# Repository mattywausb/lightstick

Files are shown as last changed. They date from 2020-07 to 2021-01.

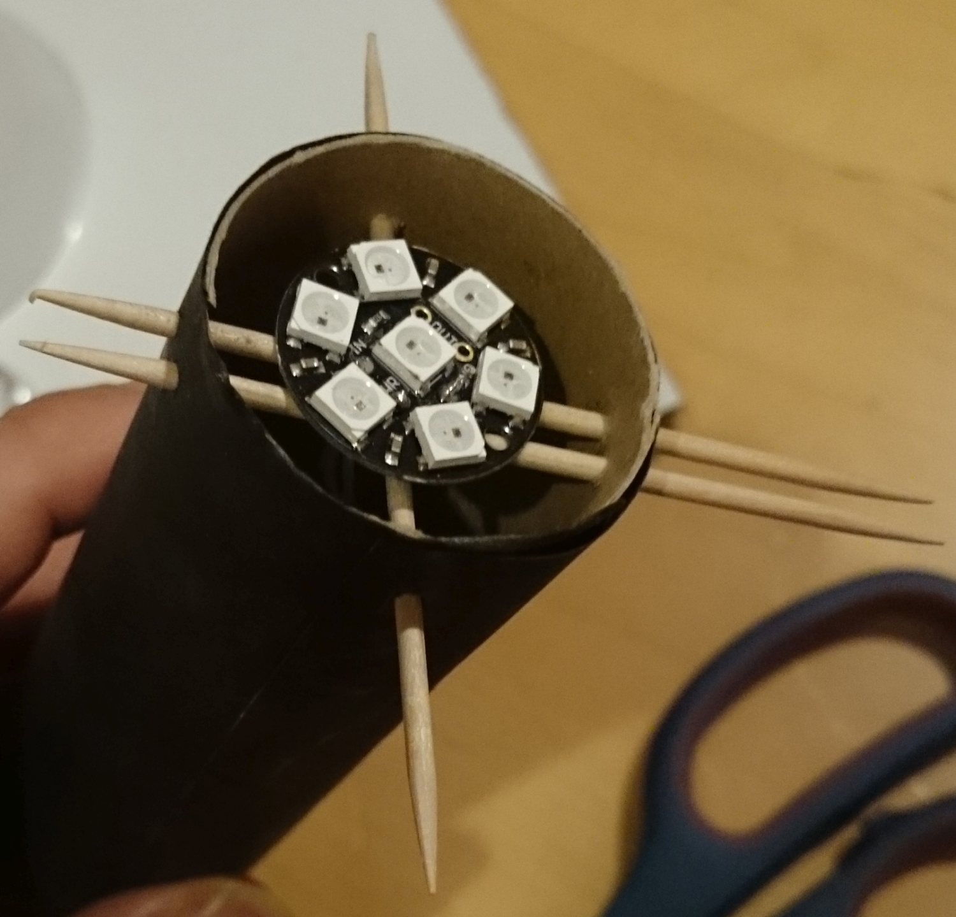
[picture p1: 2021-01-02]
docs/Head_assembly_1.jpg

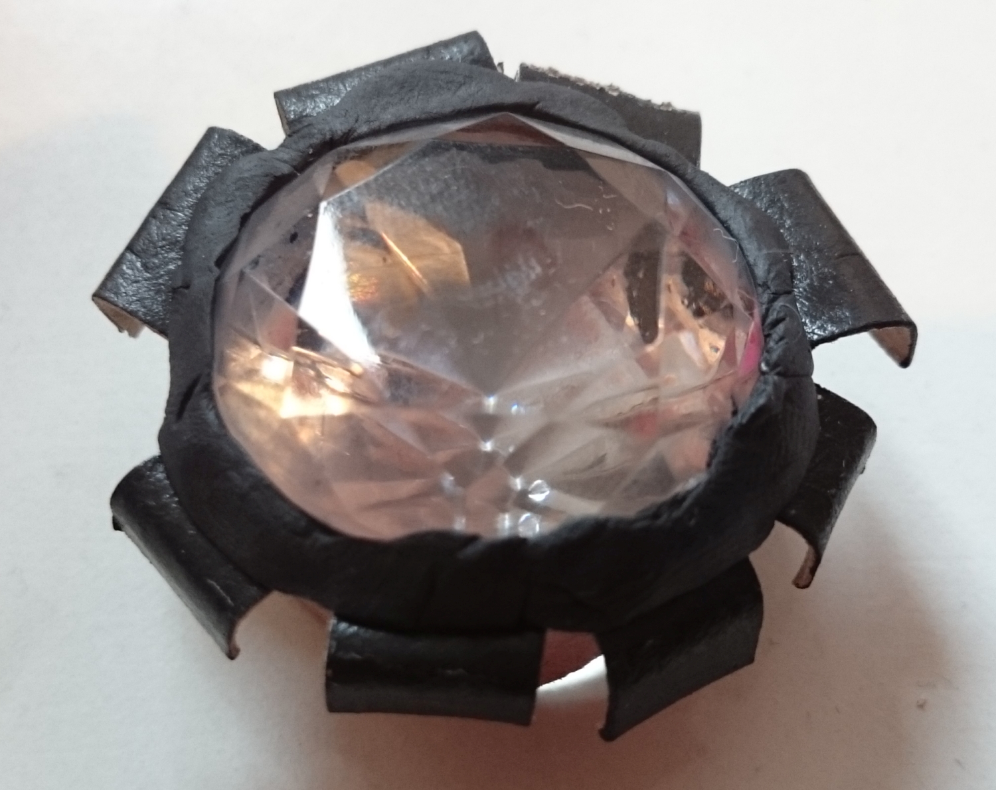
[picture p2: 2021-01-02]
docs/Optical_unit_using_CardboardSUGRU.jpg

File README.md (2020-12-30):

# ElBanquos K-Pop Lightstick
A DIY "ightstick" with multiple light effects and song specific light show presets

# Motivation
My daughter and her friends are huge fans of K-POP music and wanted to have these fancy light sticks, that are common in the concerts of K-POP groups. To be independent from an provider and restricted to one group, we decided to make our own with the following features
* Lot's of different multicolor light patterns to choose from
* Song specific presets, to have pattern changes aligned with the music 
* Smartphone compatible webinterface for song selection and pattern programming
* BPM Detection and synchronization with integrated button
* on the fly programming of new light shows over web interface
* save and load songs to/from the flash memory
* connects to existing WLAN or creates its own Access Point

# Material
* ESP8266 NodeMCU Board or D1 Mini
* Neopixel Jewel
* Pushbutton
* Small USB Power Pack or long USB Cable
* Tube that can hold NODEMCU and power pack
* small facette crystal
* transparent sphere

For more information check out my [arduino project page]( https://create.arduino.cc/projecthub/mattywausb/k-pop-lightstick-personal-lightshow-641dac)

# Software Architecture
The software is split up into the following modules
* Main Module: Coordination of processing time, Translation of input events (Button, Serial Input) into changes of pattern, Mangement of pattern sequences
* Input Module: Detection of button changes (and serial input if activated)
* WebUi Module: Redering of the WebUI and translation of WebUI Form Inputs to the main main module and management of network connection
* Lamp Module: Class to model a Hue/Saturation/Value Lamp and translate color into RGB 
* Output Module: Controlling the Lamps and Pixels, Stepping and looping through a defined pattern until instructed otherwise. Contains functions for generic chase patterns and defines the available pattern presets (Chase mode, beat fraction tempo, color palette)
* Song Catalog Module: Manages reading and saving of songs patterns to the flash memory file system

# What you will find in the repository
* Main Arduino sketch for the firmware (the_light_stick)
* Arduino sketch to format and prepare the flash memory file system (song_catalog_init)
* Additional sketches for separate developtment of light pattern(Arduino UNO compatible) and web interface(only on ESP8266)
* Additional sketches for simple demos of light control and web interface
* Documentation
  * Fritzing sketch for wireing used in the implementation
  * Manuals
  * Schematic

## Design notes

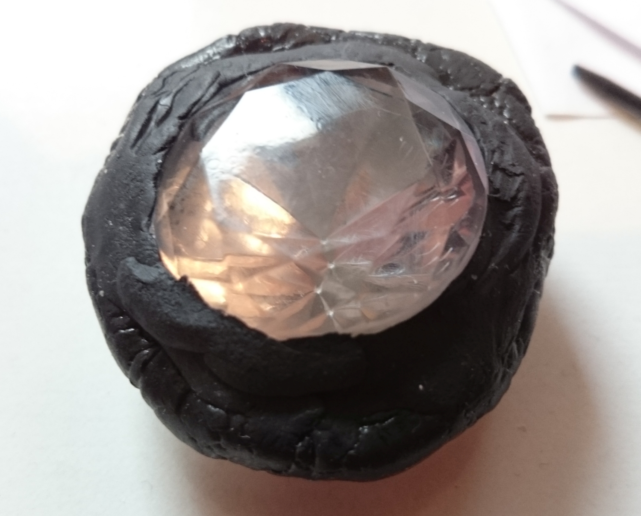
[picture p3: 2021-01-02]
docs/Optical_unit_using_FIMOSUGRU.jpg

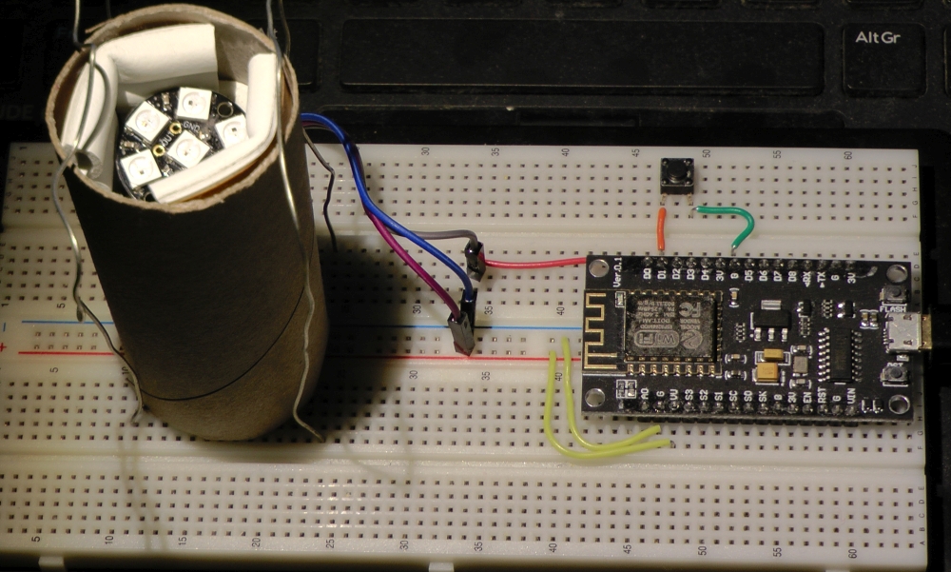
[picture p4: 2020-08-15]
docs/development_mockup.jpg

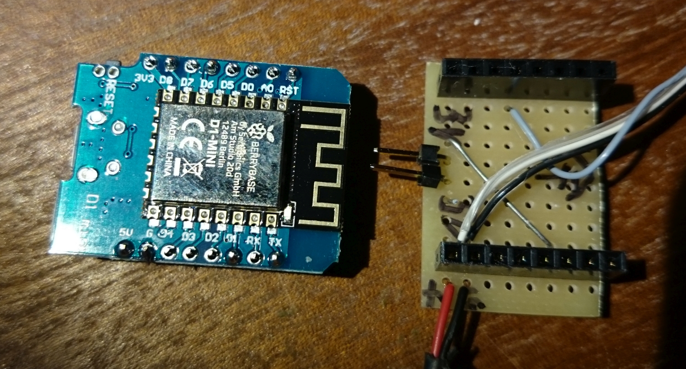
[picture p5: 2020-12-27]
docs/D1_mini_pcb_front.jpg

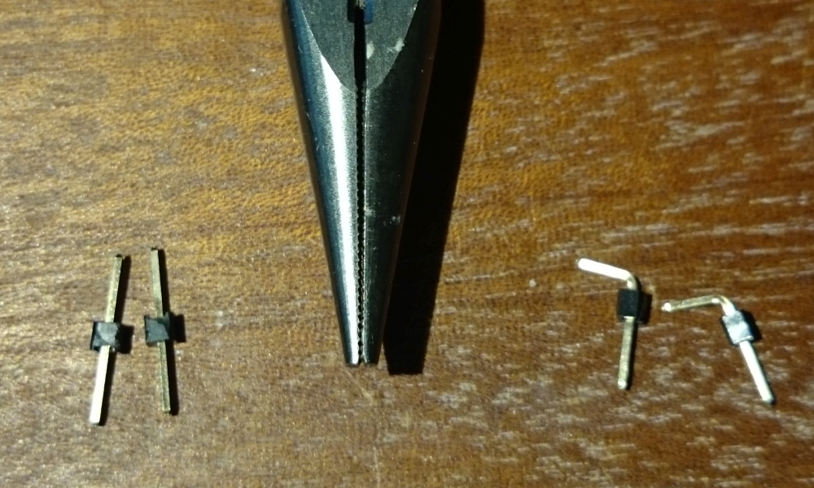
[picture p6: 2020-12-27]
docs/Crafting_button_connector.jpg

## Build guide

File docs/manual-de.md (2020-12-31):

# Personal K-Pop Lightstick - Anleitung

Mit dem "Personal K-Pop Lightstick" hat man seine eigene Lichtshow verfügbar. Im Gegensatz zu kommerziellen Produkten funktioniert er unabhängig von einer Konzertveranstaltung. Die Einstellung und Steuerung erfolgt über eine Webbrowseroberfläche. Er bietet folgende Funktionen 
* Synchronisation mit dem Beat und Musikverlauf über eingebauten Taster
* Direkte Auswahl eines Musters und Farbzusammenstellung
* Abruf von vorbereiteten Abläufen für bestimmte Lieder
* Individuelle, taktgenaue Programmierung eines Ablaufs

## Einschalten

Der Stick wird eingeschaltet, indem man den USB Stecker aus dem unteren Stabende herausholt und mit einer passenden Stromversorgung verbindet. Sofern diese kompakt genug ist, kann man sie direkt im Stick deponieren und den Deckel wieder verschließen.

Sowie der Lightstick Strom hat sucht er die Verbindung zum zuletzt kontaktierten WLAN. In dieser Zeit leuchtet er schwach in Orange. Kann er das WLAN nicht erreichen versucht er Kontakt mit einem fest codierten WLAN aufzunehmen. 
War der Verbindungsaufbau erfolgreich, wird dies durch ein schwaches grünes Blinken mitgeteilt.

Kann er kein WLAN erreichen, eröffnet der Stick eine eigene WLAN Zelle. (SSID:"Lightstick-xxxxxxxx-AP" Passwort:"letsparty" (xxxxxx=Seriennummer des eingebauten Controllers)) und ist dort unter der Adress 192.168.4.10 erreichbar.

Wenn beim Einschalten/Einstecken der USB Verbindung der Taster gehalten wird, umgeht der Stick den Versuch ein WLAN zu erreichen und baut sofort seine eigene WLAN Zelle auf.

Das ein eigenes WLAN eingerichtet wurde, wird durch ein schwaches blaues Blinken mitgetilt.

Sollte der Stick auch keinen eigenen AP aufbauen können, blink er rot und ist dann leider nicht bedienbar.

## Zugriff auf die Bedienoberfläche
Für den Zugriff benötigt man einen Browser auf einem beliebigen Gerät, das mit dem gleichen Netzwerk verbunden ist, wie der Stick.

Die im Browser einzugebende IP Adresse besteht aus 4 Zahlen, die jeweils von einem Punkt getrennt sind (z.B. 192.168.4.10) und wird vom Stick wie folgt als sich wiederholender Ablauf verschiedener Muster dargestellt.
* 8 Beats schwach grün/Blau = WLAN Modus (siehe oben)
* 2 Beats dunkel weiß>pink = Startzeichen für erste Zahl
* n rotierende Schritte in rot (n= Ziffer 1)
* 2 Beats dunkel pink 
* n rotierende Schritte in gelb (n= Ziffer 2)
* 2 Beats dunkel pink 
* n rotierende Schritte in blau (n= Ziffer 3)
* 2 Beats dunkel pink 
* 2 Beats dunkel weiß>pink = Startzeichen für zweite Zahl
* n rotierende Schritte in rot (n= Ziffer 1)
...

Um eine Null als Ziffer darzustellen wird mit einem kräftigen Pink einmal aufgeblendet. Die Ziffern 2 und 3 werden nicht genutzt, wenn sie für die Zahl nicht notwendig sind.

## Auswahl eines Pattern (Musters)
Ein Pattern definiert, welche der eingebauten LED wann und wie lange leuchten. Dies erfolgt bezogen auf den laufenden Takt, d.h. das Pattern passt sein Lauftempo der Beatzahl(BPM) an, die über den Taster ermittelt wird oder von einem vorigen Song noch eingestellt ist. 

## Zusammenstellung einer Farbpalette
Die Farbe der LED wird in der Regel durch die eingestellte Farbpalette festgelegt. Dabei wird vom eingestellten Pattern bestimmt ob mehrere Farben der Palette gleichzeitig genutzt werden und in welchem Tempo zum nächsten Platz der Palette geschaltet wird. 

Mit Auswahl einer Farbe auf der Weboberfläche wird die Farbpalette geleert und der erste Platz der Palette auf diese Farbe gesetzt. Das laufende Pattern ist dann einfarbig (Whipe wird dann nur diese Farbe zeigen). Wird das '+' Zeichen rechts neben der Farbe gewählt, so wird diese Farbe an die Palette angehängt und die Pattern greifen das entsprechend auf.

Je nach Pattern kann es interessant sein, die gleiche Farbe mehrfach hintereinander in die Palette  einzubauen. (z.B. Gelb, Blau, Blau,Blau bei "Fade", leuchtet alle 4 Beats einmal Gelb und ansonsten Blau)

### Die Pattern:
* Pulse - Kurzes Aufblitzen auf dem Beat (nutzt 2 Paletteneinträge)
* Whipe - leds innerhalb eines Beats nacheinander auf Folgefarbe schalten 
* Wave - leds nacheinander innerhalb eines Beats ein-  und im Folgebeat wieder ausschalten, dann zum nächsten Paletteneintrag wechseln
* Orbit - einfarbig rotierende Lichter. Die mittige Led blinkt auf Step 1 und 2 von 8)
* Disco - Wie Orbit, allerdings werden 3 einträge der Farbpalette auf die 3 aktiven Led verteilt
* Sparkle - Aufblitzen zufälliger LED mit einer Zufallsfarbe aus 3 Paletteneinträgen

Folgenden Pattern ignorieren die Farbpalette 

 Rainbow - Volles Farbspektrum 
 Quater - Ausschnitt aus dem Spektrum der sich dann verschiebt
 Flat - es wird nur eine Farbe des Spektrums gezeigt  und weitergeschaltet

## Synchronisationstaster
Mit dem Taster werden folgende Funktionen ausgelöst.
* 1xTippen - Beatposition festlegen / korrigieren 
* 4x regelmäßig Tippen - Tempo messen und einstellen (unregelmäßiges Tippen führt zu keiner Änderungen) 
* Halten - Aktuelles Pattern wird festgehalten. Mit Loslassen des Tasters wird das nächste Pattern gestartet

## Songprogramm abspielen
Die fest eingebauten Songs werden auf der Weboberfläche als eigene Schaltflächen angezeigt. Mit der Auswahl eines Songs wird dessen Programm sofort aktiviert, dies umfasst das korrekte Tempo (BPM) und eine Abfolge von Mustern und Farben passend zum Songverlauf.
Das Programm beginnt mit einem Muster als Wartschleife, d.h. die Abfolge wird noch nicht abgespielt sondern verweilt auf diesem ersten Muster bis der Taster gedrückt wird.

In der Regel muss der Taster auf Beat 17 (die 1 nach zweimal 8 zählern) des laufenden Songs gedrückt werden um den Ablauf passend zu starten. Die Bedienabfolge wäre also:
* Songprogramm starten (Warteschleife beginnt)
* Song im Abspielprogramm deiner Wahl starten 
* Bis Beat 16 zählen und auf dem Folgebeat den Taster bedienen

### Korrigieren
Mit einem einmaligen kurzen Druck auf den Taster kann der Beat neu synchronisiert werden. Sollte es dazu kommen, dass das Programm insgesamt gegenüber dem Ablauf verschoben ist kann mit etwas Geschickt die Position korrigiert werden.
* Lichtshow ist dem Song voraus: 2-3 Takte vor einem markanten Lichtwechsel (z.B. Refrain) den Taster drücken und halten und mit dem Beat an dem der Wechsel erfolgen soll loslassen
* Lichtshow hängt hinterher: Taster 2,5 Sekunden halten und sofort loslassen. Das Programm springt eine Position vor und ist vermutlich jetzt dem Song voraus. Deshalb gleich wieder den Taster halten und warten bis der nächste Wechsel ansteht

### Wann ist Beat 17 und warum der ?
Manche Songs haben einen Auftakt, was bei unverzüglichem Zählen der Beat zu einem Versatz in den üblichen 8er Gruppen führt. Deshalb gilt folgende Definition:

**Beat 17 ist der erste Beat nach zwei vollständigen 8er Gruppen**. 

Oder auch Beat 1 zum zählen ist der *erste Beat der ersten vollständigen 8er Gruppe*. Vortakte (z.B. die 4 Vortaktbeats von "DNA") zählen also nicht.

Beat 17 war die beste Wahl, da man so über die zwei 8er Gruppe gute Orientierung bekommt und auch bei plötzlichen Songstarts(z.B. aus einer Playlist) noch zeit hat das Programm zu wechseln während man im Kopf noch mitzählt.

Die Warteschleife und ihre Position im Song ist eine Festlegung des jeweiligen Song Programms. Für die leichtere Bedienung wurde Beat 17 festgelegt. Eigene Programme können auch andere Zählpositionen festlegen.

## Eigene Songprogamme eingeben und abspielen
Auf der Weboberfläche gibt es zwei Eingabefelder um das Songprogramm selbst festzulegen. Diese werden bei der Auswahl eines vorbereiteten Songs mit den Programmangaben für diesen Song belegt. Die beiden Textschnipsel kann man aber auch selbst dort editiern oder von einer externen Quelle hineinkopieren. Ein Songprogramm besteht aus zwei Teilen:
* Song Parts: Definieren verschiedene Sätze von Farbpaletten und Mustern die der Song nutzt
* Song Sequence: Legt das Tempo fest und regelt , welcher Song Part für wieviele Beats abgespielt werden soll

### Song Parts
Die Angabe eines Song Parts erfolgt in folgender Syntax:
```
<Part Letter><Pattern preset>/<Speed>:<Color Ppalette>

Beispiel:"A10/4:0  B42/8:2  R30/8:0"
```
* Part Letter: Ein Buchstabe unter dem dieser Part in der Song Sequence angesprochen wird. Gute Praxis sind A B C für Strophenabschnitte R S T für Refrainabschnitte, I J L M für Intro Abschnitte
* Pattern Preset: Die Nummer eines Patternpresets (Legt Pattern und Farbstepping fest)
* Speed: Tempo des Steppings innerhalb des Beats (2=2 Beats(halbe Note), 4= 1 Beat(4tel Note), 8=1/2 Beat(8tel Note), 16, 32,64
* Color Palette: Die Nummer einer der fest programmierten Farbpaletten

### Song Sequence:
Die Song Sequence repräsentiert die Abfolge des Songs. Sie beginnt mit der  BPM Angabe der dann die Songabschnitt folgen. Verschiedene Sonderzeichen markieren spezielle übergeordnete Positionen
```
<bpm> <Part Letter> <Beats><Beats>... <Part Letter>...

Beispiel: "120 A88# A88 B88 A8888 B88 R8888 8888 >A8888 B88 R8888 8888"
```

* Part Letter: Muss einer der Buchstaben aus der "Song Parts" Definition sein
* Beats: Die Beats werden als einstellige Zahlen angegeben und als solche dann für den aktuellen Abschnitt aufaddiert bis ein neuer Buchstabe den nächsten Abschnitt deklariert. (Beispiele: 8888=32 Beats 248 =14 Beats)
* Sonderzeichen #: Der Abschnitt in dem dieses Zeichen steht ist die Warteschleife. Mit dem Tastendruck springt das Programm dann zum nächsten Abschnitt. Die Anzahl an Beats in dem Abschnitt sind dabei irrelevant, sollten aber so angegeben werden, dass man ablesen kann, welcher Beat für den einsatz gewählt werden soll (88 = 16 Beats, Also Beat 17 für den Wechsel)
* Sonderzeichen >: Nach dem Songende wird an diese Stelle zurückgesprungen. So kann eine Endlosschleife einer Folge konstruiert werden. Ohne diese Angabe springt das Programm wieder an den Anfang zurück und in die ggf. dort definierte Warteschleife 

### Fehlerbehandlung
Die Angaben für Song Parts und Song Sequence werden intern bzgl. plausibilität geprüft. Formatfehler führen dazu, dass Teile ignoriert oder auch falsch zugeordnet werden. *Es gibt bisher keine Rückmeldung* ob alle Angaben korrekt waren. Syntaktisch falsche oder inkonsistente Angaben(z.B. Buchstabe doppelt als Song Part genutzt oder nicht als Songpart definiert, unbekannte Farbpalette, unbekannter Pattern Speed) führen zu verschiedenen Phänomenen: Falsche Farbpalette, Falsche Pattern, Falsche Anzahl an Beats bis zum Wechsel

## Songprogramme speichern
Ein Songprogramm kann fest in dem Stick gespeichert und dann über die Auswahlliste wieder abgerufen werden. Hierzu dienenen die Eingabefelder "Filename" und "Operation" sowei die Schaltfläche "Execute"

### Neuen Song hinzufügen
* Gewünschte Part- und Sequencedefinition müssen eingegeben und gestartet worden sein
* In "Filename" den Namen des Liedes eingeben (Buchstaben, Zahlen sowie Klammern und Bindestriche sind gestattet). Der Name wird automatisch von dem zulestzt geladenen Song vorbelegt.
* In Operation "Create" auswählen.
* Execute betätigen
Der Song sollte nun unter seinem neuen Namen in der Songprogrammliste erscheinen. Gibt es schon einen Song mit dem Namen, wird dies mit einer Meldung angezeigt und die Daten sind nicht gespeichert.

### Vorhandenen Song anpassen
* Song auswählen
* Part- und Sequencedefintionen anpassen und starten
* Der Filename sollte noch mit dem Namen des geladenen Songs besetzt sein
* In Operation "Update" auswählen
* Execute betätigen

### Vorhandenen Song löschen
* Song auswählen
* Der Filename wird mit dem Namen des geladenen Songs besetzt
* In Operation "Delete" auswählen
* Execute betätigen
Achtung: Diese Operation kann nicht Rückgängig gemacht werden
 
## WLAN Netzwerk konfigurieren
Mit den Feldern "SSID", "Password" und der Schaltfläche "connect to wifi" kann der Stick mit einem vorhandenen WLAN verbunden werden. Beim Verbindungsaufbau geht die alte Verbindung zum Stick verloren und es muss für die weitere Steuerung ein Browser im nun verbunden WLAN verwendet werden.
Sollte die Verbindung fehlschlagen und das fest einprogrammierte WLAN nicht erreichbar sein, baut der Stick wieder sein eigenes WLAN auf.
Die Darstellung von Status und IP Adresses ist identische mit der Beschreibung in "Zugriff auf die Bedienoberfläche".
 
## Anhang

### Fest programmierte Farbpaletten

```
// Code r=red o=orange y=yellow g=green c=cyan sb=sky blue b=blue pu=purple pi=pink
// prefix "l" = light   prefix"w" = White (unsaturated)
0: // Prime Colors and Yellow
1: // Police USA 
2: // Red blue variant (w,sb,r,b,o,sb,r,b) "not today"
3: // b g y
4: // Yellow pulse with blue and green change
5: // y g b c
20: // blue green
21: // blue white cyan geen
22: // blue white(on blue) cyan geen
23: // blue sky lblue cyan
40: // yellow, skyblue, orange, pink
41: // red, orange, rose
42: // pu pi wpu pi
43: // o wo o wo r wo r wo
44: // fire
45: // r wr
46: // r r r wr r r
80: // r
81: // wr
100: // blue green
101: // r wr o w+o
102: // o wo r wo wo
120: // pu pu pi pi wpu wpu pi pi
```
Weiß wird durch eine *entsättigte Farbe* dargestellt. Bei Pattern, die die Sättigung verändern ("Pulse" und "Sparkle") hat dies eine Relevanz, da dann die LED zwischen Weiß und der entsprechend unterlegten Farbe wechselt.

### Generische Farbpaletten
Bei generischen Farbpaletten werden die Farben mit der Farbpalettennummer bestimmt. Dabei gilt folgende Farbcodierung:
```
0=rot       5=cyan
1=orange    6=sky
2=gelb      7=blau
3=lemon     8=lila
4=grün      9=pink
```

#### 4 Step Paletten (10000-19999 )
Legen immer 4 Einträge in der Palette an. Die vier letzten Ziffern der Nummer bestimmen die Farbfolge.

12779 z.b. ergibt die Farbpalette;gelb blau blau pink

#### Palettengeneratoren für 1-3 Farben (20000-99000)
Palettengeneratoren erzeugen aus den Farben komplexere Farbfolgen die auch Weiß enthalten. 
Die letzten drei Ziffern definieren die zu verwendenen Farben (x y z). Sind diese all gleich, wird ein einfarbiger Generator genutzt, sind die letzten beiden Ziffern gleich, wird ein zweifarbiger Generator angesprochen, ansonsten ein Dreifarbiger.

Die ersten beiden Ziffern der Palettennummer bestimmen innerhalb der 1er,2er und,3er Farbgeneratoren den konkreten Generator aus. 
Momentan gibt es folgende Möglichkeiten
```
Einfarbig: 20-24,29
Zweifarbig: 20-36,40-43,70-73
Dreifarbig: 20-21,25-29,40-49,70-73

Beispiele:
20 Einfarbig: x wx
20 Zweifarbig: x y y
20 Dreifarbig: x y z
20333 wird zu>lemon weiß über lemon
20377 wird zu>lemon blau blau
20370 wird zu>lemon blau rot

25 Zweifarbig: wx x y y
25 Dreifarbig: wx y x z

43 Zweifarbig: wx x x x wx x x x wy y y y wy y y y
43 Dreifarbig: x y y y x y y y x z z z x z z z
```
Ein vollständiger Katalog kann nur dem Code entommen werden

### Pattern Presets
```
0-3: Pulse
4-7: Heartbeat Pulse
8-9: Dimmed Pulse, Heartbeat
10: Whipe
11: Wave
20-27: Orbit
30-37: Disco, color shift 1
40-47: "    , color shift 2
50-57: "    , color shift 3
60-67: Full Rainbow
70-77: Half  Rainbow
80-87: Quater  Rainbow
90-97: Flat (Varies in distance to next color)
100-107: Sparkle shift 1
110-117: Sparkle shift 2
120-127: Sparkle shift 3
130-133: Pulse with offbeat
134-137: Heartbeat with reverse impulse
```
Die Pattern innerhalb einer Gruppe (z.B. 0-3), varieren über die Anzahl Steps bis zum Weiterschalten einer Farbe. Dabei wird in der Regel in 2er Potenzen skaliert. So schaltet 20 bei jedem Step eine Farbe weiter, 21 jeden 2. Step, 22 jeden 4., 23 jeden 8.  Ein Song Part 20/4 schaltet also jeden Beat die Farbe voran. Ebenso 21/8 und 22/16, wobei das Muster sich aber jeweils schneller  in 1/4, 1/8 und 1/16 Noten bewegt. Mit 22/4 Schaltet die Farbe jeden 4. Beat voran, also auf jeden Takt.

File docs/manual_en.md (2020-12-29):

# Personal K-Pop Lightstick - Manual
With the "Personal K-Pop Lightstick" you have your own light show available. 
In contrast to commercial products, it works independently of a concert event. The configuration and controlling is done  via a web browser interface.
It offers the following features
* Synchronization with the beat and music history via built-in button
* Direct selection of a pattern and color combination
* Running perfect color and animation sequences for predefined songs
* Individual  programming of a color and animation sequence

## Power on

The stick is activated by opening the cover at the lower end of the stick and connecting the USB plug to a suitable power supply. 
If the powersupply is a compact power bank, you can deposit it directly in the stick and close the lid again.

As soon as the Lightstick has power, it tries to connect to a Network as follows:
* search for the previous WLAN it was connnected
* try to connect to a internally hard coded WLAN
* Open its own Access Point "Lightstick-xxxxxxxx-AP" Password: "letsparty" (This can be forced by holding the button during power on)

The finals status is presented as follows:
* low green blinking followed by IP address code= successfully connected to WIFI Connection
* low blue blinking followed by IP address code= Providing Access Point
* low red blinking: Something prevented all options

## Access the User Interface
To access the user interface open a browser on any kind of device in the same network. Type in the ip address according to the blink pattern.
An ip address consists of 4 numbers with 1 to 3 digits separated by a dot e.g. "192.168.178.18". The code is defined as follows.
* 8 Beats of low green/low blow blinks
* 2 Beats flash pink blinks = start of first number
* n rotation steps in red (n=digit 1)
* 2 Beats pink blinks
* n rotation steps in yellow (n=digit 2)
* 2 Beats pink blinks
* n rotation steps in blue (n=digit 3)
* 2 Beats pink blinks
* 2 Beats flash pink blinks = start of next number
* n rotation steps in red (n=digit 1)
* ...
In case of a zero as digit, there will always be a bright pink swipe instead of a step in the normal color. Only necessary digits are transmitted. So shot numbers will have less digits.
After presenting all numbers, the pattern will repeat with the 8 Beats for the connection status. 

## Selection of a pattern
A pattern defines which of the built-in LEDs light up when and for how long. 
This is done in relation to the current song tempo, so the pattern adapts its running speed to the number of beats per minute(BPM)  
that is determined by the button or is still set from a previous song.

## Defining a color palette
The color of the LED is usually determined by the loaded color palette. Depending on the pattern one or more 
colors of the palette are used at the same time. Also the pattern traverses through the palette after some beats.

When you select a color on the web interface, the color palette is emptied and the first place in the palette is set to this color. 
The current pattern is then monochrome (Pattern "Whipe" will then only show this color). When you use '+' sign to the right of the color,
this color is appended to the palette and the patterns take up this accordingly.

Depending on the pattern, it can be interesting to add the same color multiple times into the palette. 
(e.g. yellow, blue, blue, blue for "Wave", 1 step lights up yellow 3 steps blue)

### The Pattern:
* Pulse - Flashes on the beat (uses 2 palette entries)
* Whipe - Change LEDs to the following color one after the other within a beat
* Wabe - light leds on one after the other within a beat and turn them off again in the next beat, then switch to the next color palette entry
* Orbit - single color rotating lights. The central LED flashes on step 1 and 2 of 8.
* Disco - Like Orbit, but 3 entries of the color palette are distributed over the 3 active LEDs
* Sparkle - flashing random LED with a random color from 3 palette entries

The following patterns ignore the color palette

 Rainbow - full color spectrum
 Quater - section of the spectrum which then shifts
 Flat - only one color of the spectrum is shown and shifted in the color circle

## Synchronization button
The following functions are triggered with the button.
* 1x tap - set / correct beat position
* 4x regular tapping - measure and set the pace (irregular tapping does not result in any changes)

## Play song program
The songs, that are currently stored on the stick are displayed as separate buttons on the web interface. 
With the selection of a song, its program is activated immediately, this includes the correct tempo (BPM) and a sequence of patterns
and colors matching the course of the song. The program starts with a pattern as a waiting loop. It will not proceed to the 
next pattern until the button is pressed.

In order to synchronize the sequence appropriately, the button must be pressed  on beat 17 of the current song (the 1st beat after counting to 8 twice)
The operating sequence would be:
* Start the song program on the stick(waiting loop begins)
* Start the song in the player of your choice
* Count to beat 16 and press the button on the next beat

### Correcting the timing
The beat can be re-synchronized with a single short press of the button. Should it occour, that the program is shifted compared to the song progress, 
small deviation can be fixed.

2-3 bars before a significant light change (e.g. chorus) press and hold the button and release it on the beat at which the change should take place.

### Determining Beat 17 and why this number?
Some songs have a prelude which, if the beat is counted immediately, leads to an offset to the usual groups of 8 beats. Therefore the following definition applies:

** Beat 17 is the first beat after two complete groups of 8 **.

Or beat 1 for counting is the * first beat of the first complete group of 8 *. Pre-notes (e.g. the 4 pre-beats from "DNA") do not count.

Beat 17 was the best choice, because the two groups of 8 give you a good orientation and even if a song starts suddenly (e.g. from a playlist)
you might have time to change the program and be ready to synchronize whithout starting it over.

The waiting loop and its position in the song is a definition of the song program. Sticking to Beat 17 was set for easier operation.
Own programs can also define other counting positions, but I would not reccomend that.

## Enter your own song programs and play them
On the web interface there are two input fields to define the song program by yourself. 
When you select a prepared song, these will be set to the programming strings for this song. 
The two text snippets can also be edited there or copied from an external source. A song program consists of two components:
* Song Parts: Define different sets of color palettes and patterns that the song uses
* Song Sequence: Determines the tempo and controls which song part should be played for how many beats

### Song Parts
A song part is specified in the following syntax:
```
<Part Letter> <Pattern preset> / <Speed>: <Color P Palette>

Example: "A10/4:0 B42/8:2 R30/8:0"
```
* Part Letter: A letter which identifies this part in the song sequence. Good practice is A B C for verse sections, R S T for chorus sections, I J L M for intro sections
* Pattern Preset: The number of a pattern preset (defines pattern and color stepping, see list in Appendix)
* Speed: tempo of the stepping within the beat (2 = 2 beats (half note), 4 = 1 beat (fourth note), 8 = 1/2 beat (eighth note), 16, 32.64
* Color Palette: The number of one of the permanently programmed color palettes (see list in appendix)

### Song Sequence:
The song sequence represents the sequence of the song. It begins with the BPM declaration, which is then followed by the song sections.
Various special characters mark special locations in the sequence
```
<bpm> <Part Letter> <Beats> <Beats> ... <Part Letter> ...

Example: "120 A88 # A88 B88 A8888 B88 R8888 8888> A8888 B88 R8888 8888"
```

* Part Letter: Must be one of the letters from the "Song Parts" definition
* Beats: The beats are given as single-digit numbers and as such then added up for the current section until a new letter declares the next section. (Examples: 8888 = 32 beats 248 = 14 beats)
* Special character #: The section in which this character appears is the waiting loop. When you press the button, the program then jumps to the next section. The number of beats in the section is irrelevant, but should be specified in such a way that you can read which beat should be selected for the application (88 = 16 beats, i.e. beat 17 for the change)
* Special characters > : After the end of the song, it jumps back to this point. In this way an endless loop of a sequence can be constructed. Without this information, the program jumps back to the beginning and into the waiting loop that may have been defined there.

### Error handling
The information for Song Parts and Song Sequence is checked internally for plausibility. Format errors lead to parts being ignored or incorrectly assigned.
* Up to now there is no message in the UI that will inform you  whether all information was correct *. 
Syntactically incorrect or inconsistent information (e.g. letters used twice as song part or not defined as song part, unknown color palette,
unknown pattern speed) lead to various phenomena: wrong color palette, wrong pattern, wrong number of beats until the change. So if something weird happens, 
check the programming strings

## Store new songs
you can store and modify the songs in the internal flash memory of the stick by using the "Filename", "Operation" and "Execute" elements.
Before storing a Part / Sequence Setting make sure, to activate the current version with the "Start" button.
To prevent accidential overwriting or deletion, you need to select these operations explcitly, when needed, before hitting "Execute".

## Configure WiFi Network
To Enter or change the WiFi to connect to, the SSID and Password must be entered in the corresponding fields.
By starting the connection, the access to the userinterface gets lost and you need to user a browser in the tartge Network, to access the Userinterface again. 
See the description about network status and IP Adress presentation in the "Power on" section above.

## Appendix

###Permanently programmed color palettes###

```
// Code r = red o = orange y = yellow g = green c = cyan sb = sky blue b = blue pu = purple pi = pink
// prefix "l" = light prefix "w" = White (unsaturated)
0: // Prime Colors and Yellow (Same as 12740)
1: // Police USA
2: // Red blue variant (w, sb, r, b, o, sb, r, b) "not today"
3: // b g y
4: // Yellow pulse with blue and green change
5: // y g b c
20: // blue green
21: // blue white cyan geen
22: // blue white (on blue) cyan geen
23: // blue sky lblue cyan
40: // yellow, skyblue, orange, pink
41: // red, orange, rose
42: // pu pi wpu pi
43: // o where o where r where r where
44: // fire
45: // r wr
46: // r r r wr r r
80: // r
81: // wr
100: // blue green
101: // r wr o w + o
102: // o where r where where
120: // pu pu pi pi wpu wpu pi pi
```
White is represented by a * desaturated color *. This is relevant for patterns that change the saturation ("Pulse" and "Sparkle"),
since the LED then changes between white and the corresponding color.

### Generic color palettes ###
For generic color palettes, the colors are determined using a one digit color palette number:
```
0 = red     5 = cyan
1 = orange  6 = sky
2 = yellow  7 = blue
3 = lemon   8 = purple
4 = green   9 = pink
```

#### 4 step pallets (10000-19999)
Always creates 4 entries in the palette. The last four digits of the number determine the color sequence.

Example: 12779 gives the color palette; yellow blue blue pink

#### pallet generators for 1-3 colors (20000-99000)
Palette generators use the colors to create more complex color sequences which may also contain white.
The last three digits define the colors to be used (x y z). If these are all the same, a single-color generator is used, 
if the last two digits are the same, a two-color generator is addressed, otherwise a three-color generator.

The first two digits of the pallet number determine the specific generator within the 1, 2 and 3 color generators.
There are currently the following options implemented
```
One color: 20-24, 29
Two color: 20-36, 40-43, 70-73
Three color: 20-21, 25-29, 40-49, 70-73

Examples:
20 One color: x wx
20 Two color: x y y
20 Three color: x y z
20333 becomes> lemon white over lemon
20377 becomes> lemon blue blue
20370 becomes> lemon blue red

25 Two color: wx x y y
25 Three color: wx y x z

43 Two color: wx x x x wx x x x wy y y y wy y y y
43 Three color: x y y y x y y y x z z z x z z z
```
A complete catalog can only be obtained from the code in the output.ino module

### Pattern Presets
```
0-3: pulse
4-7: Heartbeat Pulse
8-9: Dimmed Pulse, Heartbeat
10: Whipe
11: Wave
20-27: orbit
30-37: Disco, color shift 1
40-47: ", color shift 2
50-57: ", color shift 3
60-67: full rainbow
70-77: Half Rainbow
80-87: Quater Rainbow
90-97: Flat (Varies in distance to next color)
100-107: Sparkle shift 1
110-117: Sparkle shift 2
120-127: Sparkle shift 3
```
The patterns within a group (e.g. 20-27) vary over the number of steps until the next palette color is taken. 
This is usually scaled in powers of 2. So 20 advances one color with each step, 21 advances each second step, 22 each 4th, 23 each 8th. 
A song part 20/4 advances the color each beat. 21/8 and 22/16 will do the same, but the pattern moves faster in 1/4, 1/8 and 1/16 notes.
With 22/4 the color advances every 4th beat, i.e. every measure.

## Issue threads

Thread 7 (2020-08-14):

Refactor Timing to high resultion and central Beat event management

mattywausb, 2020-08-14:
Currently the timing is calculated in milliseconds.  This will result in loss of presicion depending on the BPM (e.g, at 110BPM a beat takes 545,454545 ms, so we lose 1 ms every 2 Beats. The smaller the Beat fraction, the bigger the error. The drift will add up to noticable amounts.

The current central beat clock only defines the beginning of a pattern. All further timing is only caclulated by the pattern and will drift from central beat.

To work against this problem, the central beat clock must provide a event for every beatfraction to sync on and should use micro second resolution to provide a more accurate  beat timing.
All Pattern must synchronize to the central beat fraction as whenever possible.

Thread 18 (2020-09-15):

Declaration of major Sog steps

mattywausb, 2020-09-15:
To provide a better control when forewarding in a song sequence, it should be possible to declare major blocks.
The skipping operation (Hold button for long time and release) should switch to the next block instead of the next pattern

Ideas: colon between each Block: "A888 B1C4D3 : R8888 S888T4S4"

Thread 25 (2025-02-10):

Instructions for dummies

Collegedale-Academy-STEAM, 2025-02-10:
Is it possible to add instructions for how to import the code into arduinoIDE or whatever is best to use. I have a couple of high school students who would like to create this project but the variety of code files is a little overwhelming. Even when they import the additional files into the tabs, it gives a lot of error codes related to input setup, etc. I'm not sure they've done this part correctly because my class is a maker class, not a programming class, so coding isn't my specialty. Any tips or more tutorials available for that part?

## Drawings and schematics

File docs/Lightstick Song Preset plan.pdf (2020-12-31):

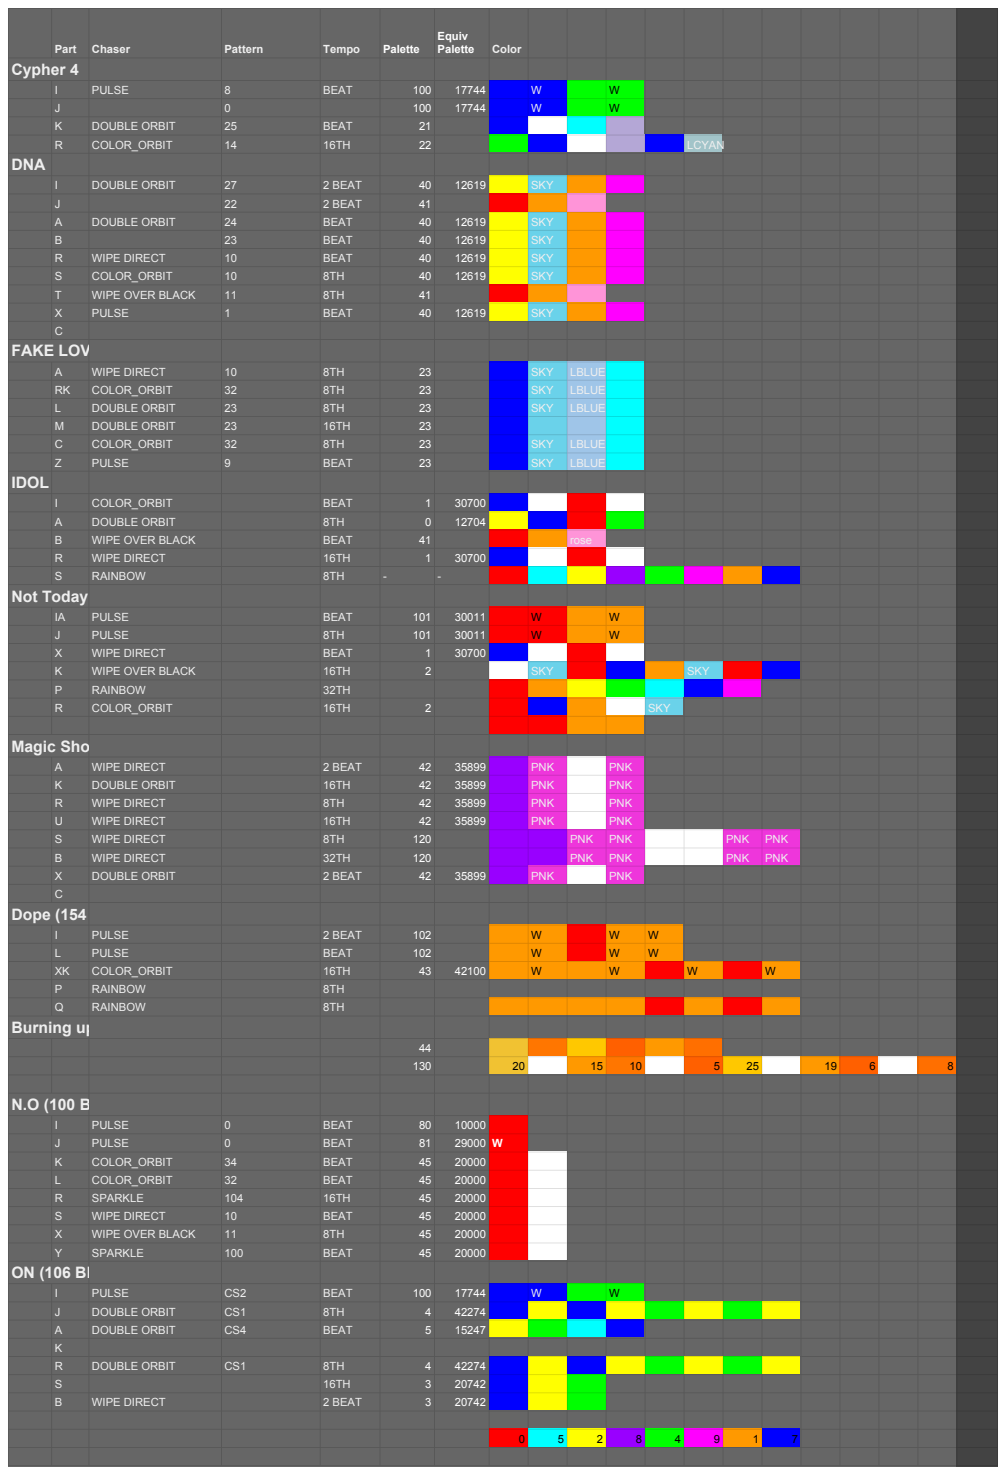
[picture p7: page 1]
Part; Chaser; Pattern; Tempo; Palette; Equiv Palette; Color; Cypher 4; PULSE; BEAT; DOUBLE ORBIT; COLOR_ORBIT; LCYAN; DNA; 2 BEAT; SKY; WIPE DIRECT; WIPE OVER BLACK; C FAKE LOVE; LBLUE; IDOL; rose; RAINBOW; Not Today; Magic Shop (75BPM); PNK; C Dope (154 BPM); N.O (100 BPM); SPARKLE; ON (106 BPM)

Burning up(100 BPM)

# Palette circle

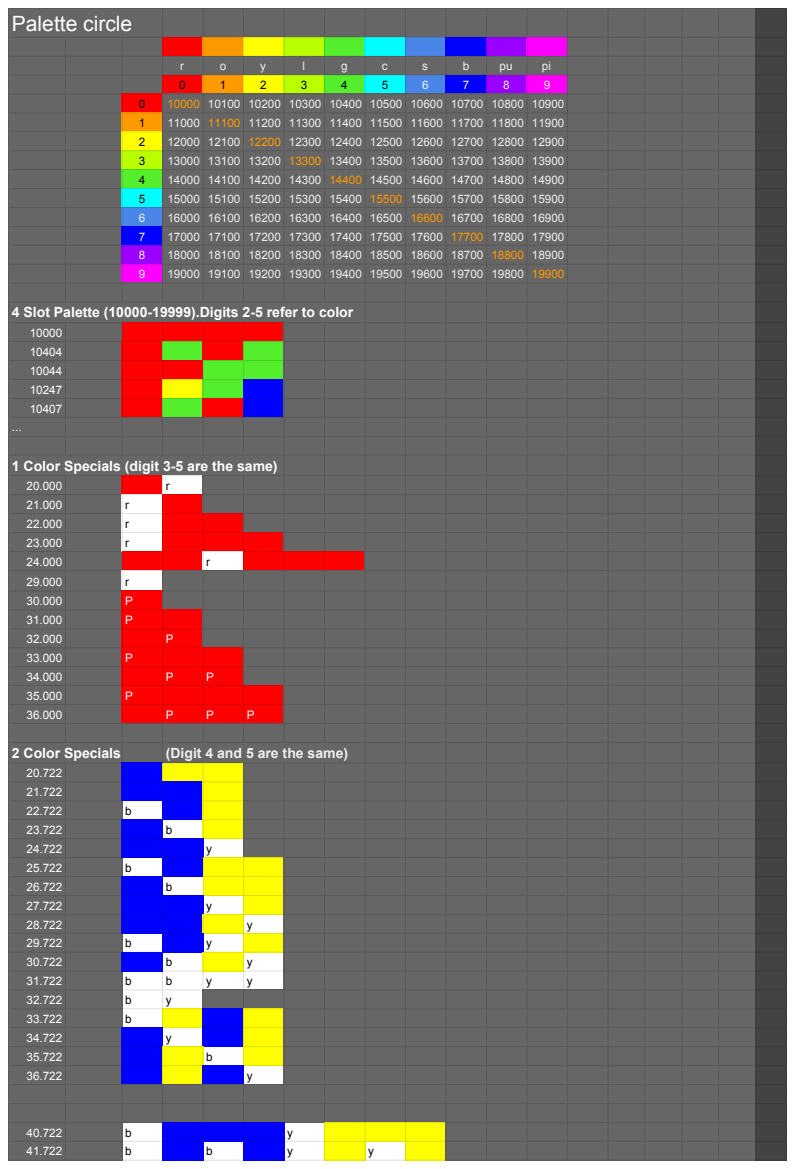
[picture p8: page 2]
2 Color Specials; (Digit 4 and 5 are the same)

r o y l g c s b pu pi

0 | 10000 10100 10200 10300 10400 10500 10600 10700 10800 10900
1 | 11000 11100 11200 11300 11400 11500 11600 11700 11800 11900
2 | 12000 12100 12200 12300 12400 12500 12600 12700 12800 12900
3 | 13000 13100 13200 13300 13400 13500 13600 13700 13800 13900
4 | 14000 14100 14200 14300 14400 14500 14600 14700 14800 14900
5 | 15000 15100 15200 15300 15400 15500 15600 15700 15800 15900
6 | 16000 16100 16200 16300 16400 16500 16600 16700 16800 16900
7 | 17000 17100 17200 17300 17400 17500 17600 17700 17800 17900
8 | 18000 18100 18200 18300 18400 18500 18600 18700 18800 18900
9 | 19000 19100 19200 19300 19400 19500 19600 19700 19800 19900

4 Slot Palette (10000-19999).Digits 2-5 refer to color

1 Color Specials (digit 3-5 are the same)

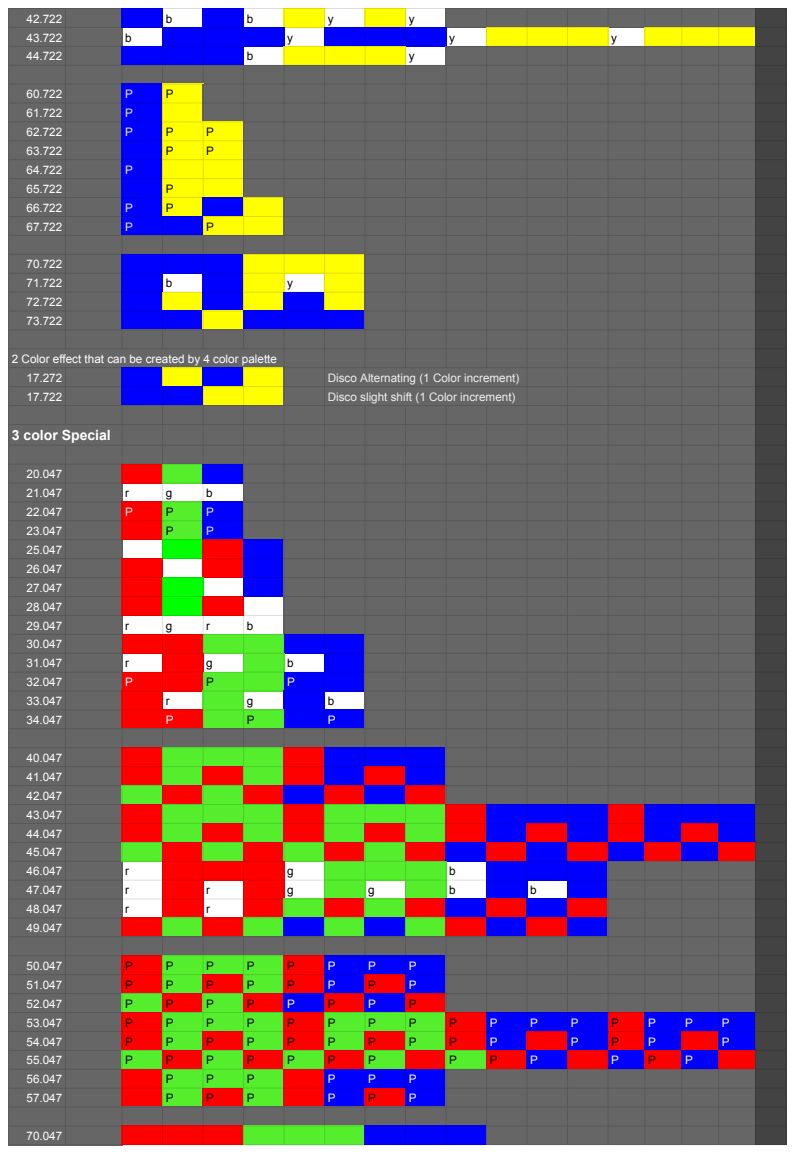
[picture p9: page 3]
Disco Alternating (1 Color increment); Disco slight shift (1 Color increment); 3 color Special

2 Color effect that can be created by 4 color palette

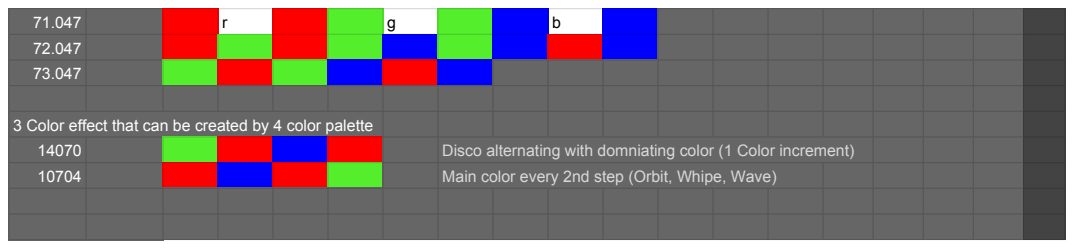
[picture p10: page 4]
Disco alternating with domniating color (1 Color increment); Main color every 2nd step (Orbit, Whipe, Wave)

3 Color effect that can be created by 4 color palette

Basetime | 15000000
bpm | 122

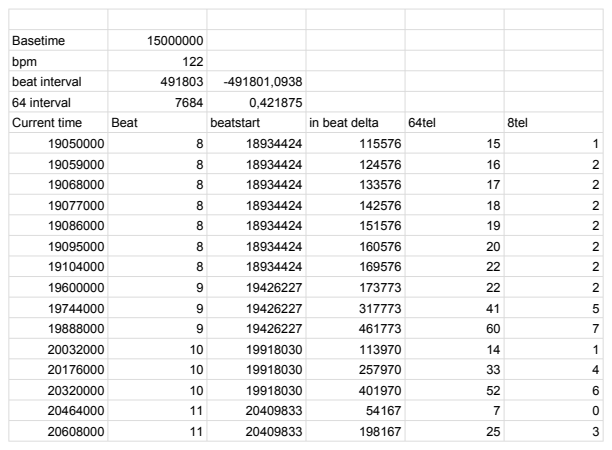
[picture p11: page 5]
beat interval; 64 interval; Current time; Beat; beatstart; in beat delta; 64tel; 8tel

Chaser | Tempo
WIPE OVER BLACK | 2 BEAT
WIPE DIRECT | BEAT
DOUBLE ORBIT | 8TH
COLOR_ORBIT | 16TH
PULSE | 32TH
RAINBOW | 64TH

### SPARKLE

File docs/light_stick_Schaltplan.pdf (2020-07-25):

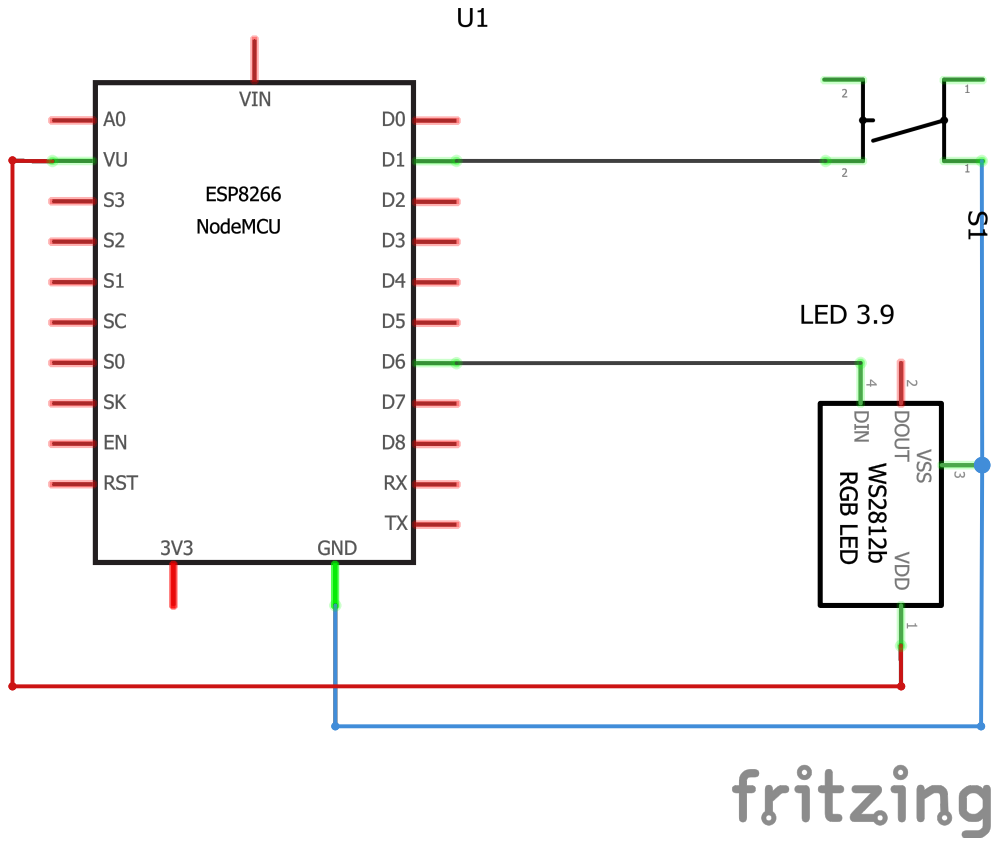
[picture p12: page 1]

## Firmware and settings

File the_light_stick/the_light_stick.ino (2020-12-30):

/* Profiles:  NodeMCU 1.0 | WeMos D1 R1 */

/* Main controller Module
 *  
 *  Orchestrates all Elements 
 *  transforming input signals from Buttons, Web IU and Serial Input into Actions and Mode changes
 *  manage output processing
 *  
 */

#include <Adafruit_NeoPixel.h>
#include "lamp.h"
#include "output.h"
#include "mainSettings.h"
#include "webui.h"



#ifdef TRACE_ON
//#define TR_SEQUENCE_PROGRESS
//#define TR_STRING_PARSING
//#define TR_WATCH_MODE_CHANGE
//#define TR_BUTTON_INPUT

#endif

typedef struct {
    char slot_tag; // 
    byte pattern_id;       // 0-255
    byte preset_speed_id;       // 0-255
    long color_palette_id;
} t_program_slot;

t_program_slot g_program_slot[MAX_NUMBER_OF_PROGRAM_SLOTS]={ /* IDOL 126 BPM*/
                              {'I',97,STEP_ON_BEAT,0}
                              ,{'A',25,STEP_ON_8TH,0}
                              ,{'B',11,STEP_ON_BEAT,41}
                              ,{'R',10,STEP_ON_16TH,1}
                              ,{'S',97,STEP_ON_16TH,0}
                              ,{PROGRAM_TAG_OFF,0,0,STEP_ON_8TH}
                              ,{PROGRAM_TAG_OFF,0,0,STEP_ON_8TH}
                              ,{PROGRAM_TAG_OFF,0,0,STEP_ON_8TH}
                              }; // String o  I98/4:0  A25/8:0 B11/8:41  R10/16:1 S98/8:0    
      //  Test String o A6/4:20 B10/8:40

int g_program_slot_count=0;                  

typedef struct {
    byte slot_index; // 
    int beats_to_run;       // 0-255
} t_program_sequence;


int g_program_sequence_loop_entry_index=1;
int g_program_sequence_hold_entry_index=0;
int g_program_sequence_length=5;


t_program_sequence g_program_sequence [MAX_NUMBER_OF_PROGRAM_SEQUENCE_STEPS] = {
                      {0,16},{1,64},{2,32},{3,32},{4,32}
                      }; // Full Version: s 126 I88# >A8888 8888 B8888 R8888 S8888 A8888 8888 B8888 R8888 S8888 B8888 R8888 S8888 A8888 

// Pattern Slots: o A6/4:20 B10/4:40 C11/8:40 D65/4:40
// Sequence setting: s80 A1# B44 >C8 D8                     
                        
int g_sequence_entry_count=8;
int g_sequence_index=0;

long g_music_start_time=0;
int g_preset_selected = 7;

int g_tap_track_interval[3];
int g_tap_track_count=0;
int g_tap_track_index=0;
int g_tap_track_sum=0;
unsigned long g_tap_track_prev_time=0L;


enum MODE_OF_OPERATION {
  MODE_SEQUENCE,
  MODE_SEQUENCE_HOLD,
  MODE_FIX_PRESET,
};

MODE_OF_OPERATION mode_of_operation=MODE_SEQUENCE;
#ifdef TR_WATCH_MODE_CHANGE
MODE_OF_OPERATION prev_mode_of_operation=MODE_SEQUENCE;
#endif


void setup() {
  #ifdef TRACE_ON 
    char compile_signature[] = "--- START (Build: " __DATE__ " " __TIME__ ") ---";   
    Serial.begin(115200);
    Serial.println(compile_signature); 
  #endif
  output_setup();
  output_set_bpm(80);
  output_reset_color_palette(HUE_ORANGE,1);
  output_start_pattern(9);  // Heartbeat with low light
  mode_of_operation=MODE_FIX_PRESET;
  input_setup();
  song_catalog_setup();
  
  input_switches_scan_tick();
  
  #ifdef TRACE_ON
    if( input_stepIsPressed()) Serial.println(F("TRACE_ON> Button is pressed during start"));
    else Serial.println(F("TRACE_ON> normal start"));
  #endif  
  
  webui_setup(input_stepIsPressed());
  
}


/* convert pattern_speed to pattern_speed_id */
int preset_speed_to_id(String pattern_speed) {
    #ifdef TR_STRING_PARSING
 //        Serial.print(F("TR_STRING_PARSING> preset_speed_to_id:"));Serial.println(pattern_speed);
  #endif
      switch(pattern_speed.toInt()) {
        case 2: return STEP_ON_2BEATS; 
        case 4: return STEP_ON_BEAT;
        case 8: return STEP_ON_8TH;
        case 16:  return STEP_ON_16TH;
        case 32:  return STEP_ON_32RD;
        case 64:  return STEP_ON_64TH;
      }
      return -1;
}

void manage_tap_input() {
  int prev_tap_track_interval=g_tap_track_interval[g_tap_track_index];

  if(++g_tap_track_index>=3) g_tap_track_index=0;  // Foreward track array index

  // Determine tap interval
  g_tap_track_interval[g_tap_track_index]=input_getLastPressStartTime()-g_tap_track_prev_time;
  g_tap_track_prev_time=input_getLastPressStartTime();
  g_tap_track_sum+=g_tap_track_interval[g_tap_track_index];

    #ifdef TR_BUTTON_INPUT
            Serial.print(F("TR_BUTTON_INPUT> tap interval: ")); Serial.println(g_tap_track_interval[g_tap_track_index]);
    #endif
  
  if(abs(g_tap_track_interval[g_tap_track_index]-prev_tap_track_interval)>300) {  // no valid lenght compared to previous
    g_tap_track_count=1; // Reset Counter and sum to latest measure
    g_tap_track_sum=g_tap_track_interval[g_tap_track_index];
    #ifdef TR_BUTTON_INPUT
            Serial.print(F("TR_BUTTON_INPUT> Tap prev check failed by ")); Serial.println(abs(g_tap_track_interval[g_tap_track_index]-prev_tap_track_interval));
    #endif
  } else g_tap_track_count++;
  
 
  if(g_tap_track_count>=3) { // We have collected 3 valid lenght
    g_tap_track_count=3;
    int average_tap_lenght=g_tap_track_sum/g_tap_track_count;
     for (int i=0; i<3;i++) {
        if(abs(average_tap_lenght-g_tap_track_interval[i])>300) { // Reset on deviation more then 150 ms to average
                 g_tap_track_count=1;
                 g_tap_track_sum=g_tap_track_interval[g_tap_track_index];
                   #ifdef TR_BUTTON_INPUT
                      Serial.print(F("TR_BUTTON_INPUT> Tap avg check failed by ")); Serial.println(abs(average_tap_lenght-g_tap_track_interval[i]));
                   #endif
                 return; // Get  out in case of fail
        }
     }
     output_set_bpm(60000/average_tap_lenght);
     g_tap_track_count=1; // Reset Counter and sum to latest measure
     g_tap_track_sum=g_tap_track_interval[g_tap_track_index];
  }
     
}

#ifdef TR_SEQUENCE_PROGRESS
void TR_sequence()
{
  Serial.print(F("TR_SEQUENCE_PROGRESS>")); Serial.print(g_sequence_index);
  Serial.print('='); Serial.print(g_program_slot[g_program_sequence[g_sequence_index].slot_index].slot_tag);
  Serial.print(g_program_slot[g_program_sequence[g_sequence_index].slot_index].pattern_id);
  Serial.print('/'); Serial.print(g_program_slot[g_program_sequence[g_sequence_index].slot_index].preset_speed_id);
  Serial.print(':'); Serial.print(g_program_slot[g_program_sequence[g_sequence_index].slot_index].color_palette_id);
  Serial.print('*'); Serial.print(g_program_sequence[g_sequence_index].beats_to_run);
  Serial.print(F(" mode:"));Serial.println(mode_of_operation);

}
#endif

/* Function to load the slot settings  by parsing a string code 
* Syntax: <letter><pattern_id>/<speed>:<color palette id> ...
* <pattern_id>: declares the pattern id (0-99)
* <speed>: declares the pattern speed as 2 4 8 16 32 64 
* <color palette id>: declares the color palette id (0-255)
*/


void parse_slot_settings(String slot_setting_string)  {
  int slot_index=0;
  int pattern_id=-1;
  int preset_speed_id=-1;
  long color_palette_id;
  int slash_index;
  int colon_index;
  int token_end_index;
  String current_token;
  #ifdef TR_STRING_PARSING
         Serial.print(F("TR_STRING_PARSING> slot settings to parse:"));Serial.println(slot_setting_string);
  #endif
  for(int char_index=0;char_index<slot_setting_string.length();char_index++) {
    if(slot_setting_string.charAt(char_index)>='A') { // new slot letter in string
        for (token_end_index=char_index+1; token_end_index<slot_setting_string.length() && slot_setting_string.charAt(token_end_index)<'A';token_end_index++); // search for end of token
        current_token=slot_setting_string.substring(char_index,token_end_index);
         #ifdef TR_STRING_PARSING
            Serial.print(F("TR_STRING_PARSING> current_token:"));Serial.println(current_token);
          #endif
        slash_index=current_token.indexOf('/');
        if (slash_index>0) { // dash to separate the speed exists
          colon_index=current_token.indexOf(':',slash_index);
          if(colon_index>0) {
            pattern_id=current_token.substring(1).toInt();
            preset_speed_id=preset_speed_to_id(current_token.substring(slash_index+1));
            color_palette_id=current_token.substring(colon_index+1).toInt();
            if(pattern_id>=0 && preset_speed_id>=0 && color_palette_id>=0) {  // Parameters are valid, so store it in array
              g_program_slot[slot_index].slot_tag=slot_setting_string.charAt(char_index);
              g_program_slot[slot_index].pattern_id=pattern_id;
              g_program_slot[slot_index].preset_speed_id=preset_speed_id;
              g_program_slot[slot_index].color_palette_id=color_palette_id;
              #ifdef TR_STRING_PARSING
                Serial.print(F("TR_STRING_PARSING> slot setting:"));
                Serial.print(slot_index);Serial.print("{'");Serial.print(g_program_slot[slot_index].slot_tag);
                Serial.print("',");Serial.print(g_program_slot[slot_index].pattern_id);
                Serial.print(',');Serial.print(g_program_slot[slot_index].preset_speed_id);
                Serial.print(',');Serial.print(g_program_slot[slot_index].color_palette_id);
                Serial.println("},");
              #endif
              pattern_id=-1;
              preset_speed_id=-1;
              if(++slot_index>=MAX_NUMBER_OF_PROGRAM_SLOTS) {
               #ifdef TR_WARNING
                    Serial.print(F("#!# TR_WARNING> max slots reached, last accepted token:"));Serial.println(current_token);
               #endif                    
                break;
              }
            }
          } // end colon found
         #ifdef TR_STRING_PARSING
             else {
              Serial.print(F("TR_STRING_PARSING> bad parsing slash_index, pattern_id, preset_speed_id:"));
              Serial.print(slash_index);Serial.print(',');
              Serial.print(pattern_id);Serial.print(',');
              Serial.println(preset_speed_id);
             }
         #endif
        } // end Slash found
    }  // end letter found
  } // end for char_index
  g_program_slot_count=slot_index;
}

/* Function to load the program sequence by parsing a string code 
* Syntax: <bpmdigit>{2..3}<letter>{1}<beatdigit>{1..n}
* <bpmdigit>: declars the BPM Speed
* <letter>: declares the slot_tag that is addressed 
* <beatdigit>: declares number of beats to hold the slot, consecutive digits will be added (e.g. 248=14)
* Special characters: > Mark Sequence entry to loop back (last entry counts)
*/

void parse_sequence(String sequence_string)  
{
  int newBPM=sequence_string.toInt();
  int sequence_index=0;
  int beat_sum=0;
  int slot_index=-1;
  #ifdef TR_STRING_PARSING
         Serial.print(F("TR_STRING_PARSING> sequence to parse:"));Serial.println(sequence_string);
  #endif
  g_program_sequence_hold_entry_index=-1;
  g_program_sequence_loop_entry_index=0;
  for(int char_index=0;char_index<sequence_string.length();char_index++) {
    if(sequence_string.charAt(char_index)>='A') { // new slot letter in string
      if(beat_sum>0 && slot_index>=0) { // previous phrase is complete and valid
        g_program_sequence[sequence_index].slot_index=slot_index;
        g_program_sequence[sequence_index].beats_to_run=beat_sum;
        #ifdef TR_STRING_PARSING
         Serial.print(F("TR_STRING_PARSING>sequence_index:"));Serial.print(sequence_index);
         Serial.print(F(" slot_index:"));Serial.print(slot_index);
         Serial.print(F(" beat_sum:"));Serial.println(beat_sum);
        #endif
        sequence_index++;
      }
      beat_sum=0;
      for(slot_index=g_program_slot_count-1;slot_index>=0;slot_index--) { // find proper slot
        if(sequence_string.charAt(char_index)==g_program_slot[slot_index].slot_tag) break;
      }
      #ifdef TR_STRING_PARSING
         Serial.print(F("TR_STRING_PARSING>slot_index:"));Serial.println(slot_index);
      #endif
    } // end if letter found 
    else 
    if(sequence_string.charAt(char_index)>='1' && sequence_string.charAt(char_index)<='9') { // beat digit
      beat_sum+=sequence_string.substring(char_index,char_index+1).toInt();
    } else
    if(sequence_string.charAt(char_index)=='>') {  // Loop marker
      g_program_sequence_loop_entry_index=sequence_index+1;
      #ifdef TR_STRING_PARSING
         Serial.print(F("TR_STRING_PARSING>loop entry at:"));Serial.println(g_program_sequence_loop_entry_index);
      #endif
    } else
    if(sequence_string.charAt(char_index)=='#') {  // Hold marker
      g_program_sequence_hold_entry_index=sequence_index;
      #ifdef TR_STRING_PARSING
         Serial.print(F("TR_STRING_PARSING> hold entry at:"));Serial.println(g_program_sequence_loop_entry_index);
      #endif
    }
    
  } // end loop over characters of the string
  if(beat_sum>0 || slot_index>=0) { // previous phrase is complete and valid
        g_program_sequence[sequence_index].slot_index=slot_index;
        g_program_sequence[sequence_index].beats_to_run=beat_sum;
         #ifdef TR_STRING_PARSING
         Serial.print(F("TR_STRING_PARSING> sequence_index:"));Serial.print(sequence_index);
         Serial.print(F(" slot_index:"));Serial.print(slot_index);
         Serial.print(F(" beat_sum:"));Serial.println(beat_sum);
        #endif
        sequence_index++;
      }
  g_program_sequence_length=sequence_index;
  if(g_program_sequence_loop_entry_index>=g_program_sequence_length)g_program_sequence_loop_entry_index=0;  // in case loop entry tag is placed after last valid block
  
  if(newBPM>0) output_set_bpm(newBPM);
  sequence_start();
}

void sequence_load() {
  #ifdef TR_SEQUENCE_PROGRESS
    TR_sequence();
  #endif
  output_set_pattern_speed(g_program_slot[g_program_sequence[g_sequence_index].slot_index].preset_speed_id);
  output_load_color_palette(g_program_slot[g_program_sequence[g_sequence_index].slot_index].color_palette_id);
  output_start_pattern(g_program_slot[g_program_sequence[g_sequence_index].slot_index].pattern_id);
  if(g_sequence_index==g_program_sequence_hold_entry_index){
    mode_of_operation=MODE_SEQUENCE_HOLD;
 //   #ifdef TR_SEQUENCE_PROGRESS
 //       Serial.println(F("TR_SEQUENCE_PROGRESS> Hold index reached"));
 //   #endif        
  }
  else mode_of_operation=MODE_SEQUENCE;
}

void sequence_start()
{
  #ifdef TR_SEQUENCE_PROGRESS
        Serial.println(F("TR_SEQUENCE_PROGRESS> sequence_start"));
  #endif
  g_sequence_index=0;
  sequence_load();
}

void sequence_next_slot()
{
   #ifdef TR_SEQUENCE_PROGRESS
        Serial.println(F("TR_SEQUENCE_PROGRESS> sequence_next_slot"));
   #endif
   if(++g_sequence_index>=g_program_sequence_length)g_sequence_index=g_program_sequence_loop_entry_index;
   sequence_load();
}



void loop() {
  // Check for input from webui
  webui_loop();
  
  // Manage Button Press
  input_switches_scan_tick();
  if (input_stepGotPressed()) {
      #ifdef TR_BUTTON_INPUT
        Serial.println(F("TR_BUTTON_INPUT>step got pressed"));
      #endif
      output_sync_beat(input_getLastPressStartTime());
      if(mode_of_operation==MODE_SEQUENCE_HOLD) sequence_next_slot();
      manage_tap_input();
  }

  if (input_stepIsPressed() && mode_of_operation==MODE_SEQUENCE) {
    if(input_getCurrentPressDuration()>2000) {
      mode_of_operation=MODE_SEQUENCE_HOLD;
    }
    #ifdef TR_BUTTON_INPUT
    else {
      Serial.print(F("TR_BUTTON_INPUT>step press duratio:"));Serial.println(input_getCurrentPressDuration());
    }
    #endif 
  }

  if (input_stepGotReleased()) {
   #ifdef TR_BUTTON_INPUT
        Serial.println(F("TR_BUTTON_INPUT>step got released"));
   #endif
    if(mode_of_operation==MODE_SEQUENCE_HOLD)
    {
      output_sync_beat(input_getLastPressEndTime());
      sequence_next_slot();
    }
  }
  
  

  // Manage Serial input
  #ifdef FEAT_ALLOW_SERIAL_INPUT
  /*
   * Commands:
   * x<id>               load song preset
   * o <slot settings>   load the slot settings from string syntax
   * s <sequence string> load the sequence from string syntax
   * +                   restart sequence
   * 
   * b <bpm>             set bpm
   * w {2,4,8,16,32,64}  set step speed (waittime)
   * 
   * p <pattern id>      start predefined pattern per id (0 Pulse, 10 Whipe, 
   * <id>/{2,4,8,16,32,64}  start predefined pattern per id with waittime
   * 
   * l <pallette id>     load color palette
   * C <hue>,<sat>       reset color palette and set first color
   * c [<i>:]<hue>,<sat> add color to palette or change color on palette index <i>
   * t <id>:<p1>,<p2>    start free pattern: 
   *                     0=PULSE <steps_until_next_color>,<follow_up_tick_count>
   *                     1=WHIPE <over_black>
   *                     2=DOUBLE ORBIT <steps_until_next_color>
   *                     3=COLOR ORBIT <steps_until_next_color>,<color_palette_increment>
   *                     6=RAINBOW <distance>, <increment>
   */
  input_pollSerial();
  if(input_newSerialCommandAvailable()) {
    String command=input_getSerialCommand();
    if(command.startsWith("x")) { //Load sequence from Library
      song_preset_start(command.substring(1).toInt());
    }
    if(command.startsWith("s")) { //Change sequence by string
      parse_sequence(command.substring(1));
    }
    if(command.startsWith("+")) {  // restart sequence mode
      sequence_start();
    }
    if(command.startsWith("b")) {  // b123 <- Change bpm: 
      int bpm=command.substring(1).toInt();
      if(bpm>0) output_set_bpm(bpm);
    }

    if(command.startsWith("w")) {  // w16 <- Change waittime directly
      int preset_speed_id=preset_speed_to_id(command.substring(1));
      if(preset_speed_id>=0)output_set_pattern_speed(preset_speed_id);
      mode_of_operation=MODE_FIX_PRESET;
    }
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

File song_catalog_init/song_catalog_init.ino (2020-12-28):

/* Example showing timestamp support in LittleFS */
/* Released into the public domain. */
/* Earle F. Philhower, III <earlephilhower@yahoo.com> */

#include <FS.h>
#include <LittleFS.h>
#include <time.h>

#define SONG_DIR_NAME "/songs"
#define SONG_FILE_SEPARATOR_CHAR '&'
#define SONG_LOAD_BUFFER_LENGTH 200

// MAX STRING LENGTH                         0--------10--------20--------30--------40--------50--------60--------70--------80--------90--------100-------10--------20--------30--------40--------50--------60--------70--------80--------90--------200-------90--------90--------90--------90--------9-254
const char song_name_CYPHER4[] PROGMEM ="Cypher 4 (BTS)";
const char song_slots_CYPHER4[] PROGMEM ="I8/4:100 J0/4:100 K25/4:21 R44/16:22";
const char song_sequence_CYPHER4[] PROGMEM ="120 I88# >J888888 K8888 8888 8888 8888 R8887J1 K8888 8888 8888 8888 8888 R8887J1 K8888 8888 8888 R8888 8887J1";

const char song_name_BURNINGUP[] PROGMEM ="Burning Up (BTS)";
const char song_slots_BURNINGUP[] PROGMEM ="I0/4:44 R54/32:130 K108/16:44 Y100/32:44 P10/16:44 Q10/32:44 X0/4:44 L21/16:44 B10/8:44 T54/64:130";
const char song_sequence_BURNINGUP[] PROGMEM ="100 I88# R8888 K88 88 P888Q6X2 R8888 L88 K84Y2X2  P888Q6X2 R8888 B8884Q3X1 T8888 R8888";


const char song_name_DNA[] PROGMEM ="DNA (BTS)";
const char song_slots_DNA[] PROGMEM ="I27/4:40 J22/2:41 A24/4:40  B23/4:40 R10/4:40 S10/8:40 T11/8:41 X1:/4:40";
const char song_sequence_DNA[] PROGMEM ="130 I488 # J88 A8888 B8888 R8888  S8888 T8888  X4 A8888 8888 R8888 S8888 T8888 X8 A8888 X8 R8888 8888";

const char song_name_FAKE_LOVE[] PROGMEM ="FAKE LOVE (BTS)";
const char song_slots_FAKE_LOVE[] PROGMEM ="I11/8:23 A10/8:23 C32/8:23 L23/8:23 M23/16:23 R32/8:23 Z:9/4:23";
const char song_sequence_FAKE_LOVE[] PROGMEM ="78 I88 #A88 R4444 L4444 M4444 A4444 4444 C4444 4444 R4444 L4444 M4444 A4444 4444 C4444 4444 R4444 A4444 4444 >Z8";

const char song_name_IDOL[] PROGMEM ="IDOL (BTS)";
const char song_slots_IDOL[] PROGMEM ="I2/4:1 J44/4:1  A24/8:6 B11/8:41  R11/16:7 S95/8:0";
const char song_sequence_IDOL[] PROGMEM ="126 I88# J88 A8888 8888 B8888 R8888 S8888 A8888 8888 B8888 R8888 S8888 B8888 R8888 S8888";

const char song_name_NOT_TODAY[] PROGMEM ="Not Today (BTS)";
const char song_slots_NOT_TODAY[] PROGMEM ="I2/4:11010 J2/4:29100 H1/8:29100 X:10/4:1 K11/16:2 P62/32:2 O68/8:2 Q68/16:2 R55/16:2";
const char song_sequence_NOT_TODAY[] PROGMEM ="110 I88# J84H2X2 K8888 K8888 P888O4Q4 R8888 8888 K8888 P888O4Q4 R8888 8888 I8884H4 R8888 8888";

const char song_name_MAGIC_SHOP[] PROGMEM ="Magic Shop (BTS)";
const char song_slots_MAGIC_SHOP[] PROGMEM ="I2/4:42 J34/4:42  A10/2:42 K25/16:42 R10/8:42 U10/16:42 S10/8:120 B10/32:1202";
const char song_sequence_MAGIC_SHOP[] PROGMEM ="75 I4444# J4444 K4444 4444 R4444 44 U44 S4444 4444 A4444 K4444 4444 R4444 44U44 S4444 4444 R4444 444B4 S4444 R4444 4444 4444";

const char song_name_DOPY[] PROGMEM ="Dope (BTS)";
const char song_slots_DOPY[] PROGMEM ="I3/4:11010 J0/4:102 L1/4:102 M102/4:102 K44/16:43 P63/8:0 Q68/8:0";
const char song_sequence_DOPY[] PROGMEM ="154 I88# J88 J8888 K8888 8888 8888 P8888 88Q88 K8888 8888 M8888 K4L4K4L4K8L8 P8888 88Q88 K8888 8888 P8888 88Q88 K8888 M8";

const char song_name_NO[] PROGMEM ="N.O (BTS)";
const char song_slots_NO[] PROGMEM ="I0/4:80 J0/4:81 K34/4:45 L32/4:45 R104/16:45 S10/4:45 X11/8:45 Y100/4:45";
const char song_sequence_NO[] PROGMEM ="147 I88 #J88 K8888 L8888 8888 R8888 S8888 8888 K8888 L8888 8888 R8888 S8888 8888 Y88 X86R2 X86R2 X86I2 X86I2 Y8888";

const char song_name_ON[] PROGMEM ="ON (BTS)";
const char song_slots_ON[] PROGMEM ="I2/4:100 J23/16:3 A23/4:5 B22/4:5 R23/16:3 S11/16:4 C10/2:3";
const char song_sequence_ON[] PROGMEM ="106 I88 #J881 A8888 B8888 R8888 S8888 B8888 8888 R8888 S8888 C8 C8888 R8888 S8888 S8888";

const char song_name_DEMO__[] PROGMEM ="-- full demo --";
const char song_slots_DEMO__[] PROGMEM ="A1/4:0 B5/4:0 C10/4:0 D11/8:0 D24/4:0 E34/4:0 F68/8:0";
const char song_sequence_DEMO__[] PROGMEM ="120 A8888 B8888 C8888 D8888 E8888 F8888";


struct catalog {
  const char *song_name;
  const char *song_slot_definition;
  const char *song_sequence_definition;
} const song_catalog[] PROGMEM = {
   {song_name_BURNINGUP,song_slots_BURNINGUP,song_sequence_BURNINGUP}
  ,{song_name_CYPHER4,song_slots_CYPHER4,song_sequence_CYPHER4}
  ,{song_name_DNA,song_slots_DNA,song_sequence_DNA}
  ,{song_name_DOPY,song_slots_DOPY,song_sequence_DOPY}
  ,{song_name_FAKE_LOVE,song_slots_FAKE_LOVE,song_sequence_FAKE_LOVE}
  ,{song_name_IDOL,song_slots_IDOL,song_sequence_IDOL}
  ,{song_name_MAGIC_SHOP,song_slots_MAGIC_SHOP,song_sequence_MAGIC_SHOP}
  ,{song_name_NOT_TODAY,song_slots_NOT_TODAY,song_sequence_NOT_TODAY}
  ,{song_name_NO,song_slots_NO,song_sequence_NO}
  ,{song_name_ON,song_slots_ON,song_sequence_ON}
  ,{song_name_DEMO__,song_slots_DEMO__,song_sequence_DEMO__}
};

int song_catalog_count=11;



String song_catalog_status_message="";
boolean song_catalog_has_error=false;

String song_catalog_current_name="";
String song_catalog_current_slots="";
String song_catalog_current_sequence="";

Dir song_catalog_dir;


void setup() {
  Serial.begin(115200);
  song_catalog_setup() ;
  if(song_catalog_has_error) {
    Serial.print("song_catalog_error:");
    Serial.println(song_catalog_status_message);
  } else {
    listDirToSerial("/");
  }
}


// -------------- Song catalog functions ---------------------

void song_catalog_setup() {
Serial.println("Mount LittleFS");
  if (!LittleFS.begin()) {
    song_catalog_status_message="Could not open filesystem";
    song_catalog_has_error=true;
    Serial.println("LittleFS mount failed");
    return;
  }
}


void song_catalog_goto_start() {
  song_catalog_dir = LittleFS.openDir(SONG_DIR_NAME);
}

boolean song_catalog_next() {
  if (song_catalog_dir.next()) {
    song_catalog_current_name=song_catalog_dir.fileName();
    return true;
  } 
  return false;
}
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

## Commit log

2020-07-21 Keep in sync during pattern change. Sync bew by button.
2020-07-21 BPM determination with button taps
2020-07-23 Added ESP pin annotation
2020-07-25 Bugfix about button,
    better tracing for button input
    [LightShow_preparation.ino, input.ino, lamp.cpp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]
2020-07-25 Fixed serial interface for esp Initialize with IDOL song sequence
    [LightShow_preparation.ino, input.ino, the_light_stick.ino]
2020-07-25 Added fritzing
    [light_stick.fzz]
2020-07-26 Basic program / Program slot mechanics implemented
2020-07-28 Slot setup string input implemented
2020-08-01 Slot programming with string adapted to new color palette concept
2020-08-01 bug fix in slot search while parsing sequence
    [LightShow_preparation.ino, output.ino]
2020-08-02 Renamed Trace Tags, added API Call Trace for color
2020-08-02 Bugfix for color orbit
    [LightShow_preparation.ino, output.ino]
2020-08-06 Rework of ui started
    [webui.ino]
2020-08-08 Changed switches to have >> as fast version
2020-08-09 Hold Button feature added
2020-08-09 merged hold button to main code
2020-08-10 Manual-de complete
2020-08-10 manual de seems to be complete for now
2020-08-10 Merged tested code to ui_preparation. Modified ui prototype with BPM and Wifi Form
2020-08-12 Switched back tracing to normal
2020-08-14 Rearranged pattern and color buttons in prototype
2020-08-14 ui_preparation tested with new button layout
2020-08-14 Return of state fix
    [webui.ino]
2020-08-16 Organize documentation, enhance schematicy
    [light_stick.fzz]
2020-08-21 Added URL to arduino page
2020-08-21 Fixet sparkle_start, not initializing palette index
    [output.ino]
2020-09-26 We mOs D1 Test sucessfull Changed schematic for D1 Wemos and added minimal measures
2020-12-25 Added Trace for Stylesheet request
2020-12-27 Added D1 PCB Setup pictures
2020-12-28 Prototyped file storage for presets
2021-01-02 Added more assembly pictures
